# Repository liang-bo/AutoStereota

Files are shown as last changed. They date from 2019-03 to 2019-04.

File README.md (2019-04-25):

# AutoStereota

Gradient index (GRIN) lenses can be used to image deep brain regions
otherwise inaccessible via standard optical imaging methods. Brain tissue aspiration
before GRIN lens implantation is a widely adopted approach. However, typical brain
tissue aspiration methods still rely on a handheld vacuum needle, which is subjective to
human error and low reproducibility. Therefore, a high-precision automated surgical
instrument for brain tissue aspiration is desirable.
We developed a robotic surgical instrument that utilizes robotic control of
a needle connected to a vacuum pump to aspirate brain tissue. The system was based
on a commercial stereotaxic instrument, and the additional parts can be purchased offthe-
shelf or Computer Numerical Control (CNC) machined. A MATLAB-based userfriendly
graphical user interface (GUI) was developed to control the instrument.
Our robotic surgical instrument is an ideal solution for brain tissue
aspiration prior to GRIN lens implantation. It will be useful for neuroscientists performing
in vivo deep brain imaging using miniature microscope or two-photon microscope
combined with microendoscopes.

- Automated surgical instrument for brain tissue aspiration
- Simply modified from commercial stereotaxic instrument
- Open-source user friendly GUI software in MATLAB
- Gradient index lens or micro-prism implantation for in vivo calcium imaging
- Minimize human error, reduce training time, and increase surgical precision

# References

Bo Liang, Lifeng Zhang, Casey Moffitt, Yun Li, Da-Ting Lin,
An open-source automated surgical instrument for microendoscope implantation,
Journal of Neuroscience Methods,
Volume 311,
2019,
Pages 83-88,
ISSN 0165-0270,
https://doi.org/10.1016/j.jneumeth.2018.10.013.
(http://www.sciencedirect.com/science/article/pii/S0165027018303212)

Also see:

Giovanni Barbera, Bo Liang, Lifeng Zhang, Charles R. Gerfen, Eugenio Culurciello, Rong Chen, Yun Li, Da-Ting Lin,
Spatially Compact Neural Clusters in the Dorsal Striatum Encode Locomotion Relevant Information,
Neuron,
Volume 92, Issue 1,
2016,
Pages 202-213,
ISSN 0896-6273,
https://doi.org/10.1016/j.neuron.2016.08.037.
(http://www.sciencedirect.com/science/article/pii/S089662731630530X)

Bo Liang, Lifeng Zhang, Giovanni Barbera, Wenting Fang, Jing Zhang, Xiaochun Chen, Rong Chen, Yun Li, Da-Ting Lin,
Distinct and Dynamic ON and OFF Neural Ensembles in the Prefrontal Cortex Code Social Exploration,
Neuron,
Volume 100, Issue 3,
2018,
Pages 700-714.e9,
ISSN 0896-6273,
https://doi.org/10.1016/j.neuron.2018.08.043.
(http://www.sciencedirect.com/science/article/pii/S0896627318307724)

Lifeng Zhang, Bo Liang, Giovanni Barbera, Sarah Hawes, Yan Zhang, Kyle Stump, Ira Baum, Yupeng Yang, Yun Li, Da‐Ting Lin,
Miniscope GRIN Lens System for Calcium Imaging of Neuronal Activity from Deep Brain Structures in Behaving Animals,
Current protocols in neuroscience,
Volume 86, Issue 1,
2019,
Pages e56
ISSN 1934-8584,
https://doi.org/10.1002/cpns.56
(https://currentprotocols.onlinelibrary.wiley.com/doi/full/10.1002/cpns.56)

https://github.com/giovannibarbera/miniscope_v1.0

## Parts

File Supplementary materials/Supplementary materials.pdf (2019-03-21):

## Journal of Neuroscience Methods 311 (2019) 83–88

## An open-source automated surgical instrument for microendoscope implantation

Bo Lianga,1,*

, Lifeng Zhanga,1,*
, Casey Moffitta

, Yun Lia,b

, Da-Ting Lina,c

a Intramural Research Program, National Institute on Drug Abuse, National Institutes of Health, 333 Cassell Drive, Baltimore, MD, 21224, United States

b Department of Zoology and Physiology, University of Wyoming College of Arts and Sciences, Laramie, WY, 82071, United States

c The Solomon H. Snyder Department of Neuroscience, Johns Hopkins University School of Medicine, Baltimore, MD, 21205, United States

* Corresponding authors.

E-mail addresses: liangb227@gmail.com (B. Liang), lfzhang916@hotmail.com (L. Zhang).

1 These authors contributed equally to this work.

https://doi.org/10.1016/j.jneumeth.2018.10.013

Part list

| Name | Company | Catalog number | Quantity | Link
1 | Stepper motor | Phidgets | 3326_0 | 3 | 42STH38 NEMA-17 bipolar stepper motors with 14:1 gearbox https://www.phidgets.com/?tier=3&catid=24&pcid=21&prodid=345
2 | Stepper motor controller | Phidgets | 1067_0 | 3 | PhidgetStepper Bipolar HC https://www.phidgets.com/?tier=3&catid=23&pcid=20&prodid=1029
3 | Motor-Stereotaxic Adapter | Custom design | N/A | 3 | The adapters were CNC-machined (Millitnow.com); The 3D models are also included here. (Solidworks and STEP files) https://github.com/liang-bo/AutoStereota
4 | Shaft coupler | AliExpress | N/A | 3 | 5*8mm Motor shaft Rigid Steel coupling https://www.aliexpress.com/item/5-8mm-Motor-shaft-Rigid-Steel-coupling-8mm-A-Diameter-5mm-B-Diameter-16mm-OD-22m/1566611975.html (https://www.aliexpress.com/item/5-8mm-Motor-shaft-Rigid-Steel-coupling-8mm-A-Diameter-5mm-B-Diameter-16mm-OD-22m/1566611975.html) or ones with similar specs
5 | M3 x 8mm Socket Head Screws | Thorlabs or McMaster-Carr | N/A | 12 | https://www.mcmaster.com/standard-socket-head-screwshttps://www.thorlabs.com/thorproduct.cfm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 or ones with similar specs
6 | Software | Developed in MATLAB (Mathworks, MA) environment. | N/A | N/A | https://github.com/liang-bo/AutoStereota
7 | Small animal stereotaxic instrument | Kopf | Model 963 | 1 | Ultra-Precise Micro Manipulator Model 961 / 10 micron resolution, all axes, including
8 | Mini-USB Cable 60cm 24AWG | Phidgets | 3036_0 | 4 | https://www.phidgets.com/?tier=3&catid=28&pcid=24&prodid=186 or ones with similar specs
9 | PhidgetInterf aceKit 8/8/8 w/6 Port Hub | Phidgets | 1019_1B | 1 | https://www.phidgets.com/?tier=3&catid=96&pcid=76&prodid=1035 or ones with similar specs
10 | Power adapter | Phidgets | 3024_1 | 1 | https://www.phidgets.com/?tier=3&catid=61&pcid=54&prodid=175 or ones with similar specs

## STEP #1. Disassemble the knobs of manipulators

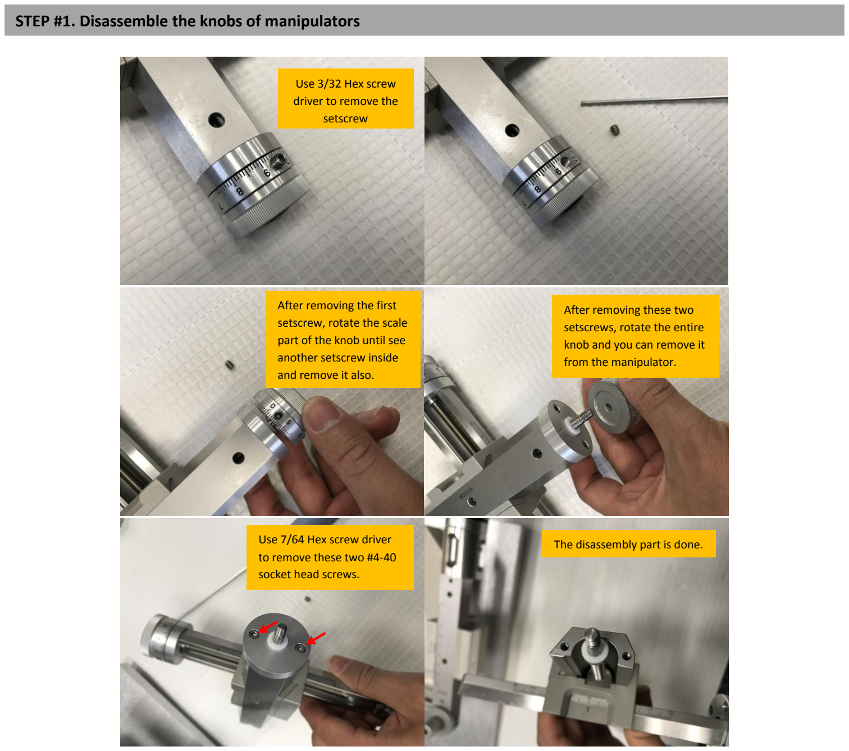
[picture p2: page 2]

Use 3/32 Hex screw
driver to remove the
setscrew

After removing the first
setscrew, rotate the scale part of the knob until see another setscrew inside
and remove it also.

After removing these two
setscrews, rotate the entire knob and you can remove it from the manipulator.

Use 7/64 Hex screw driver
to remove these two #4-40
socket head screws.

The disassembly part is done.

## STEP #2. Mount the stepper motors

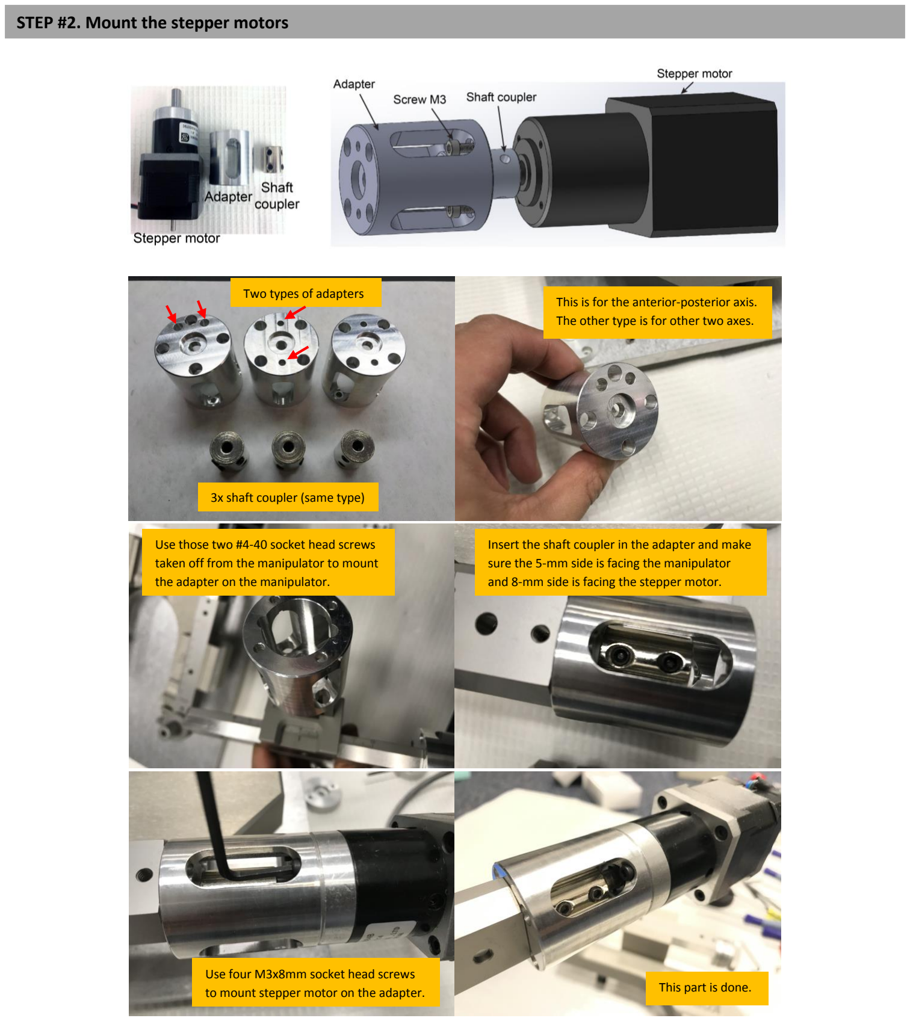
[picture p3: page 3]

Two types of adapters

3x shaft coupler (same type)

This is for the anterior-posterior axis. The other type is for other two axes.

Use those two #4-40 socket head screws taken off from the manipulator to mount the adapter on the manipulator.

Insert the shaft coupler in the adapter and make sure the 5-mm side is facing the manipulator and 8-mm side is facing the stepper motor.

Use four M3x8mm socket head screws
to mount stepper motor on the adapter. | This part is done.

## STEP #3. Wiring diagram

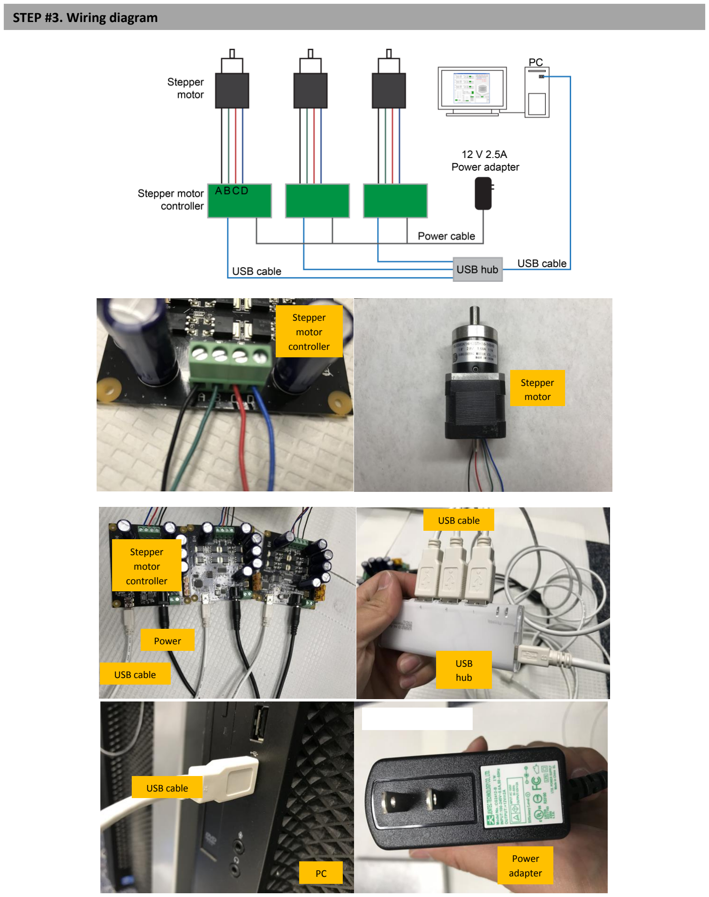
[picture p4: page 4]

PC

Stepper
motor
controller

Power
adapter

USB
hub

USB cable

USB cable

Power

Stepper
motor
controller

Stepper
motor

USB cable

## 1. Install Phidget drivers: click Phidget-x64_2.1.8.20150109.exe https://www.phidgets.com/downloads/phidget21/libraries/windows/Phidget-x64/

2. Install Matlab Compiler Runtime V8.4 for Windows 64 bit OS: Click MCR_R2014b_win64_installer.exe

## https://www.mathworks.com/products/compiler/matlab-runtime.html

## 3. Install AutoStereota: Click AutoStereotaInstaller_MCR.exe https://github.com/liang-bo/AutoStereota/Installer/

4. Warning: DO NOT CHANGE THE DEFAULT PATH!!! AutoStereota MUST BE INSTALLED IN C:\Program

## Files\AutoStereota\ 5. Calibration: 1) Open C:\Program Files\AutoStereota\application\Para.ini

2) Change the values as indicated by the red box. These are the serial numbers of the three stepper motor controllers. You can find them on the PCB board corresponding to each axis. (See below figures). Row#1: lateralmedial axis; Row#2: dorsal-ventral axis; Row#3: anterior-posterior axis;
3) Change the values as indicated by the green box. These are the readout values from the manipulators.

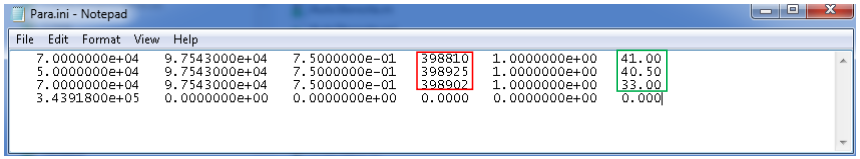
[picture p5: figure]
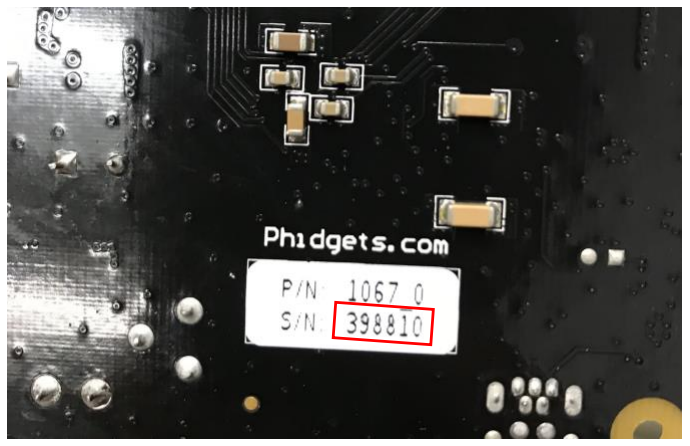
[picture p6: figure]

## 6. Finally you can launch AutoStereota! (Connect to the power first!)

## STEP #4. Software installation and configuration

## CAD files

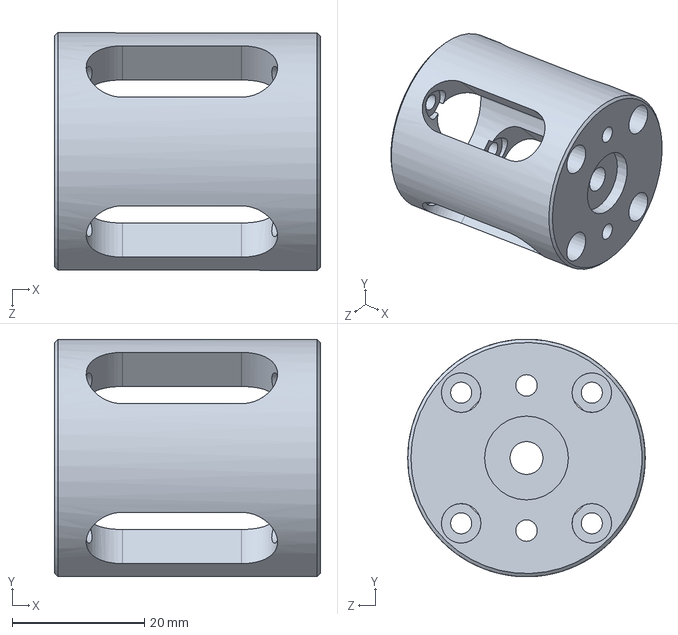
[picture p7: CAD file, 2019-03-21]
3DModel/Connector1.SLDPRT
40.3 x 36.0 x 36.0 mm

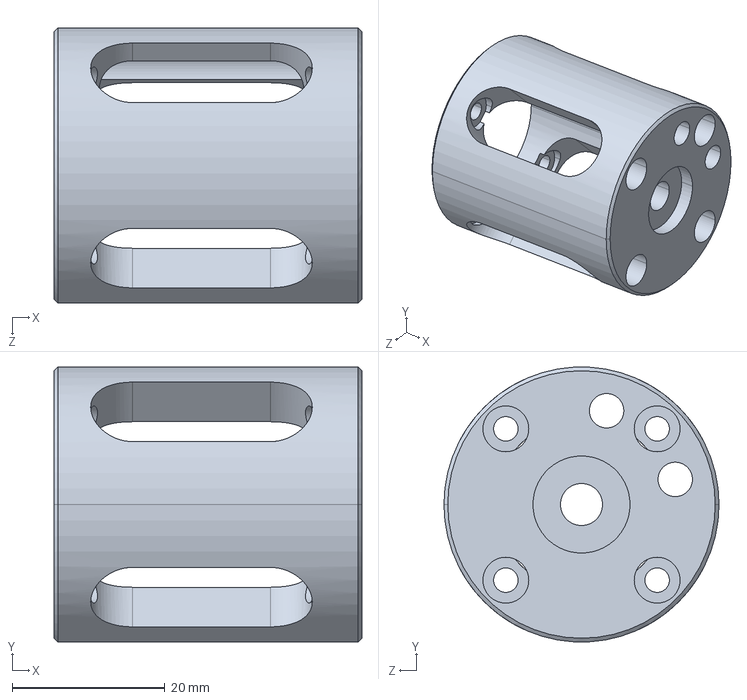
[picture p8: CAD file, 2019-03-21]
3DModel/Connector2_AP203.STEP
40.3 x 35.9 x 36.0 mm

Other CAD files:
AutoStereota/phidget21_thunk_pcwin64.obj
3DModel/Connector1_AP214.STEP
3DModel/Connector1_AP203.STEP
3DModel/Connector2_AP214.STEP
3DModel/Connector2.SLDPRT

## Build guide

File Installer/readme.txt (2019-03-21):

The packaged installer can be downloaded here:
https://drive.google.com/open?id=1CIiZ1T5qlAqV1y0mDZCF8DJ2XJT1dNo2

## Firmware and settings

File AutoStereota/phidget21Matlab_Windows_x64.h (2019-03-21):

/*
* Phidget21 Header for Matlab
*/
#ifndef WIN32
#define __stdcall
#endif

#ifndef PHIDGET_H
#define PHIDGET_H 

#if !defined(__int64) 
#if !defined(__BORLANDC__) && !defined(_MSC_VER) 
typedef long long __int64; 
#endif 
#endif

 /*! \mainpage Phidget21 C API Documentation
  *
  * Describes the Application Program Interface (API) for each Phidget device.  
  * The API can be used by a number of languages; 
  * this manual discusses use via C and the code examples reflect this.
  *
  * \section howto_sec How to use Phidgets
  Phidgets are an easy to use set of building blocks for low cost sensing and control from your PC.  
  Using the Universal Serial Bus (USB) as the basis for all Phidgets, the complexity is managed behind 
  this easy to use and robust Application Program Interface (API) library.

  The library was written originally for Windows, but has been ported to MacOS and Linux.  
  Although the library is written in C, the functions can be called from a number of languages including C#, C/C++, Java, Python, Visual Basic, and many more.  
  The full library source is not available for all platforms - however, the Linux distribution contains all platform independent code.

  See the <a class="el" href="modules.html">Modules</a> section for the API documentation.

  See \ref phidcommon for calls common to all phidgets.

  Refer to the User Guide for your device and the 
  <a class="el" href="http://www.phidgets.com/docs/General_Phidget_Programming" target="_blank">General Phidget Programming</a> page for more detailed, language inspecific API documentation and examples. 
  You can download a set of C/C++ example code from the Quick Downloads section of the <a class="el" href="http://www.phidgets.com/docs/Language_-_C/C%2B%2B#Quick_Downloads" target="_blank"> C/C++ Language Page</a>.

  \section general_sec General Usage
  Phidgets in C are accessed/controlled via handles. Every Phidget has it's own Handle, as well as a generic Phidget handle. These handles are simply pointers
  from the user's perspective - internally, they point to structures. Almost every function in the API takes a Phidget handle as the first argument.

  phidget21.h contains the API calls for all Phidgets. It should be included in any programs which need to access the Phidget C Library from C/C++.

  Note that this file is not distributed in the source, this file is generated from the source using the C preproccessor. It is installed with the libraries.

  The first step is to create the handle. Every phidget has it's own _create function. This creates space for the structure internally and gives you a 
  valid Handle for passing to all other Phidget functions.

  The next step is to register event handlers. These need to be registered now, because they only throw events in the future, 
  and if they are registered later, you will miss events. Every Phidget event takes a Phidget handle, a function callback pointer and
  a user defined pointer, which is passed back from within the callback.

  The next step is to open the Phidget. This is done with either \ref CPhidget_open, \ref CPhidget_openRemote or \ref CPhidget_openRemoteIP, depending on whether you want
  to open the Phidget locally or over the network. Open returns right away (is asynchronous) so you have to either wait for the attach event, 
  or call \ref CPhidget_waitForAttachment before using the handle further.

  The next step it to actually use the Phidget. Once attached, all functions can be called. Device specific handles should be cast to \ref CPhidgetHandle for use
  with the common API functions.

  Once finished, you should call first \ref CPhidget_close and then \ref CPhidget_delete to clean up the connection to the Phidget and the Handle before exiting.

  \section return_sec Return Codes
  Every Phidget function returns an int. A return code of 0 means success, anything else means failure. The failure codes are documented here: \ref phidconst.

  When a value is unknown, in addition to returning an error code, the pointer will be set to one of the unknonwn values documented here: \ref phidconst.
  *
  */

/** \defgroup phidgets Specific Phidgets
 */


/** \defgroup phidcommon Phidget Common
 * These calls are common to all Phidgets objects. See the <a class="el" href="http://www.phidgets.com/docs/General_Phidget_Programming" target="_blank">General Phidget Programming</a> page for more in-depth usage instructions and examples.
 * @{
 */

/**
 * A phidget handle.
 */
typedef int *CPhidgetHandle;

/**
 * Timestamp structure - usually initialized to 0.
 */
typedef struct _CPhidget_Timestamp
{
 int seconds;			/**< Number of seconds since timing began */
 int microseconds;		/**< Number of microseconds since last second passed - range is 0 - 999999 */
} CPhidget_Timestamp, *CPhidget_TimestampHandle;


/** \addtogroup phidconst
 * @{
 */

/**
 * Phidget device class uniquely identifies a class of Phidgets.
 */
typedef enum
{
 PHIDCLASS_ACCELEROMETER = 2,			/**< Phidget Accelerometer */
 PHIDCLASS_ADVANCEDSERVO = 3,			/**< Phidget Advanced Servo */
 PHIDCLASS_ANALOG = 22,					/**< Phidget Analog */
 PHIDCLASS_BRIDGE = 23,					/**< Phidget Bridge */
 PHIDCLASS_ENCODER = 4,					/**< Phidget Encoder */
 PHIDCLASS_FREQUENCYCOUNTER = 21,		/**< Phidget Frequency Counter */
 PHIDCLASS_GPS = 5,						/**< Phidget GPS */
 PHIDCLASS_INTERFACEKIT = 7,				/**< Phidget Interface Kit */
 PHIDCLASS_IR = 19,						/**< Phidget IR */
 PHIDCLASS_LED = 8,						/**< Phidget LED */
 PHIDCLASS_MOTORCONTROL = 9,				/**< Phidget Motor Control */
 PHIDCLASS_PHSENSOR = 10,				/**< Phidget PH Sensor */
 PHIDCLASS_RFID = 11,					/**< Phidget RFID */
 PHIDCLASS_SERVO = 12,					/**< Phidget Servo */
 PHIDCLASS_SPATIAL = 20,				/**< Phidget Spatial */
 PHIDCLASS_STEPPER = 13,				/**< Phidget Stepper */
 PHIDCLASS_TEMPERATURESENSOR = 14,		/**< Phidget Temperature Sensor */
 PHIDCLASS_TEXTLCD = 15,				/**< Phidget TextLCD */
 PHIDCLASS_TEXTLED = 16,				/**< Phidget TextLED */
 PHIDCLASS_WEIGHTSENSOR = 17,			/**< Phidget Weight Sensor */

} CPhidget_DeviceClass;
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
